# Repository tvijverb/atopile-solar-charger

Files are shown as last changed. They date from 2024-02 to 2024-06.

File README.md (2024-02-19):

# atopile-solar-charger




## Description
### WARNING: PCB is still untested, it's being produced right now. I'll update the readme after testing.
Solar charger PCB using the Texas Instruments BQ25504. It is meant to be paired with a LIC supercap https://www.aliexpress.com/w/wholesale-lic-supercapacitor.html?spm=a2g0o.home.search.0
Pairing it with a regular 3.7V lithium battery is not recommended since the undervoltage value is too low for this chemistry.

Solar input - 3V max

Battery voltage range

| Specs | Voltage |
| --- | --- |
| Vbat_ov | 3.8 |
| Vbat_uv | 2.5 |
| Vbat_ok | 2.6 |

# Design files
The JLCPCB production files can be found in the following folder
```
elec/layout/default/production
```

## Connectors
There are 3 2-pin JST connectors with a 2mm pitch. Positive and negative pins are indicated with a + sign on the top of the PCB.
1. Solar input
2. battery connector
3. load output

## Silkscreen
The component silkscreen labels have not been modified (yet) from default settings. These will cause warnings in KiCad DRC checks.

## Atopile CI/CD
The atopile CI/CD github action pipeline will currently give errors since I used my own parts-search endpoint. This will probably be fixed in the coming weeks.

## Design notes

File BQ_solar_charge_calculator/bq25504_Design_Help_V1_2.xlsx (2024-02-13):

User Input | VBIAS | 1.25 | V
Fixed
 | Comparator threshold for VSTOR maximum. |  |  |  |  | Comparator threshold voltages indicating when |  |  |  |  | Comparator threshold for VSTOR minimum. |  |  |  |  | Maximum power point threshold, e.g. ~0.7-0.8 of
 | Typically the max storage element voltage, |  |  |  |  | VSTOR has risen above VBAT_OK_HYS or fallen |  |  |  |  | Typically the min storage element voltage, |  |  |  |  | solar panel's open circuit voltage
 | e.g. 4.2V for LiIon battery |  |  |  |  | below VBAT_OK |  |  |  |  | e.g. 2.5V for LiIon battery
 | 2.5V < VBAT_OV < 5.25V |  |  |  |  | VBAT_OV > VBAT_OK_HYST > VBAT_UV |  |  |  |  | 2.2V < VBAT_UV < VBAT_OV |  |  |  |  | MPPT
Desired |  |  |  |  |  | RSUM1 | 10 | Mohm |  |  |  |  |  |  |  | RSUM1 | 20 | Mohm
Desired | RSUM1 | 10 | Mohm |  |  | VBAT_OK | 2.6 | V | > VBAT_UV |  | RSUM1 | 10 | Mohm |  |  | VIN_DC(OC) | 2 | V | Open Circuit Volts
Desired | VBAT_OV | 3.8 | V |  |  | VBAT_OK_HYST | 2.8 | V | > VBAT_OK |  | VBAT_UV | 2.5 | V |  |  | VREF_SAMP | 1.6 | V | MPP voltage
 |  |  |  |  |  |  |  | closest 1% resistor1 |  |  |  |  |  |  |  |  |  | closest 1% resistor1
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

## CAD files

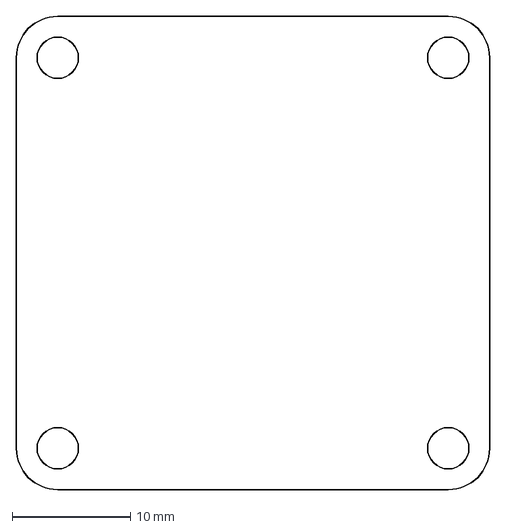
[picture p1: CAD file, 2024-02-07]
mech/template_outline.dxf
40.0 x 40.0 mm

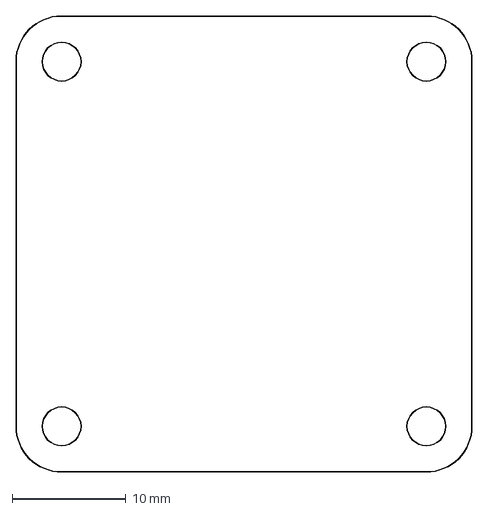
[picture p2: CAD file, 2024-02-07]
mech/template_40x40.dxf
40.0 x 40.0 mm

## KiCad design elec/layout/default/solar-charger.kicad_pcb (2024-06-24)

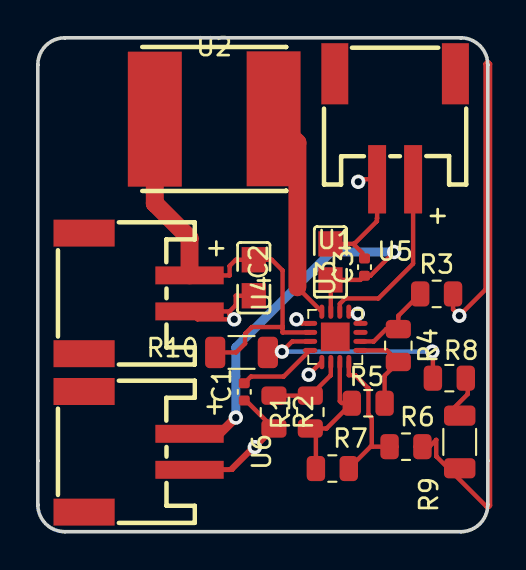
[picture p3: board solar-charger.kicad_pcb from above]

Board: 2 copper layers, 25.0 x 27.4 mm, 19 parts (0 on the bottom side), 13 nets.

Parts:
C1: 50V 10nF X7R ±10% 0402 Multilayer Ceramic Capacit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; C0402
C2: 25V 4.7uF X5R ±10% 0805 Multilayer Ceramic Capaci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; C0805
C3: 16V 100nF X7R ±10% 0402 Multilayer Ceramic Capaci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; C0402
R1: 125mW Thick Film Resistors 150V ±100ppm/℃ ±1% 5.1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; R0805
R2: 125mW Thick Film Resistors 150V ±100ppm/℃ ±1% 4.8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; R0805
R3: 125mW Thick Film Resistors 150V ±100ppm/℃ ±1% 4.4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; R0805
R4: 125mW Thick Film Resistors 150V ±100ppm/℃ ±1% 4.7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; R0805
R5: 125mW Thick Film Resistors ±100ppm/℃ ±1% 715kΩ 08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; R0805
R6, R7: 125mW Thick Film Resistors ±100ppm/℃ ±1% 4.99MΩ 0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; R0805
R8: 125mW Thick Film Resistors 150V ±100ppm/℃ ±1% 6.0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; R0805
R9: 250mW Thick Film Resistors 200V ±100ppm/℃ ±1% 10M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; R1206
R10: 250mW Thick Film Resistors 200V ±100ppm/℃ ±1% 4.0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; R1206
U1: VQFN-16_L3.0-W3.0-P0.50-TL-EP
U2: IND-SMD_L8.0-W8.0_FNR80XXS
U3: C0805
U4, U5, U6: CONN-SMD_P2.00_S2B-PH-SM4-TB-LF-SN

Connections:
_1: R10.2, U1.2, U2.1, U3.1, U4.1
gnd: C1.2, C2.2, C3.2, R2.2, R3.2, R6.2, R9.2, U1.1, U1.5, U1.12, U1.13, U3.2, U4.2, U5.2, U6.2
lbst: U1.16, U2.2
ok_hyst: R4.2, R5.1, U1.9
ok_prog: R3.1, R4.1, U1.10
p2: R8.2, R9.1
vbat: U1.14, U5.1
vbat_ov: R1.2, R2.1, U1.6
vbat_uv: R6.1, R7.2, U1.8
vcc: C2.1, C3.1, U1.15, U6.1
voc_samp: R8.1, R10.1, U1.3
vrdiv: R1.1, R5.2, R7.1, U1.7
vref_samp: C1.1, U1.4

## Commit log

2024-02-07 Configure project
    [solar-charger.kicad_pcb, solar-charger.kicad_sch]
2024-02-07 solar side done
    [solar-charger.kicad_pcb]
2024-02-12 design v3
    [solar-charger.kicad_pcb]
2024-02-13 v1 solar PCB
    [bq25504_Design_Help_V1_2.xlsx, solar-charger.kicad_pcb]
2024-06-24 solar charger fix gnd connections
    [solar-charger.kicad_pcb]
2024-06-24 update backside graphics
    [solar-charger.kicad_pcb]
